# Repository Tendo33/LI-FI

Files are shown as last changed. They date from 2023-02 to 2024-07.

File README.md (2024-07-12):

# Li-Fi (Light Fidelity): Visible Light Communication Based on STM32

Innovative advancements in wireless communication have led to the development of Li-Fi, a technology that harnesses the power of visible light for data transmission. Li-Fi, or Light Fidelity, is a form of visible light communication (VLC) that uses light-emitting diodes (LEDs) as a medium for high-speed, bidirectional data transfer. This technology leverages the rapid switching capabilities of LEDs to transmit binary information, offering a new dimension to the realm of wireless networking.

At the heart of this cutting-edge system lies the STM32 microcontroller, a powerful and versatile device developed by STMicroelectronics. The STM32 family offers a wide range of performance, power consumption, and integration options, making it suitable for various applications, including complex high-end products and low-power devices. In the context of Li-Fi, the STM32 serves as the brain that controls the modulation and demodulation of light signals, enabling efficient and reliable data communication.

The STM32 microcontroller, with its robust processing capabilities, is capable of managing the intricate details of Li-Fi communication protocols. It can handle the modulation techniques required to encode digital data onto the light waves and decode them at the receiver end. Moreover, the STM32 can support additional functionalities such as error correction, signal processing, and security features, which are crucial for maintaining high data integrity and confidentiality in Li-Fi networks.

One of the significant advantages of using Li-Fi technology over traditional Wi-Fi is the potential for higher bandwidth and data rates. Since the visible light spectrum has a much wider bandwidth than radio frequencies, Li-Fi can theoretically achieve gigabit speeds. Additionally, Li-Fi can coexist harmoniously with existing wireless technologies without causing interference, making it a promising solution for densely populated areas or environments where radio frequency emissions are restricted, such as hospitals and aircraft cabins.

The integration of Li-Fi with the STM32 microcontroller opens up exciting possibilities for various industries. From enhancing the Internet of Things (IoT) ecosystem to improving connectivity in smart homes and offices, Li-Fi powered by STM32 can revolutionize the way we interact with our environment. With its ability to provide secure, high-speed connectivity using everyday lighting fixtures, Li-Fi stands as a beacon of innovation in the field of wireless communication.

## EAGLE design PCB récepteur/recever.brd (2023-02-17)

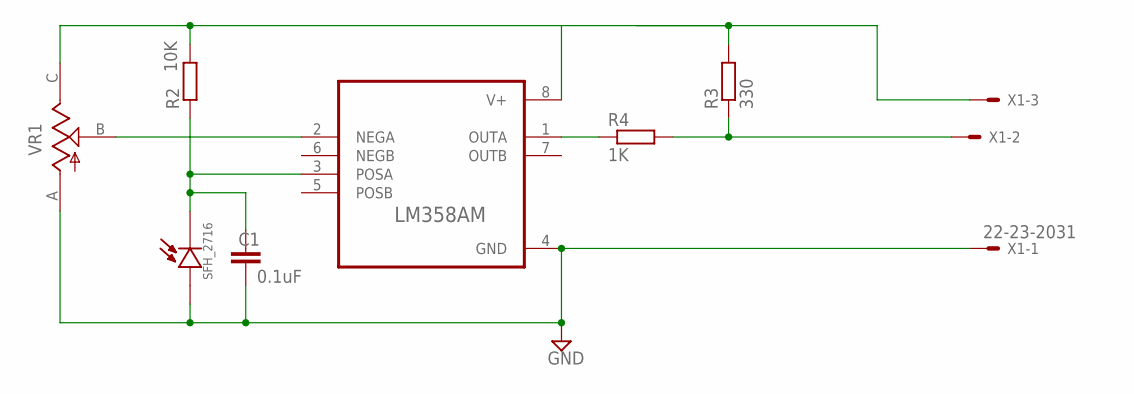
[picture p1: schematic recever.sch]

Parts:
C1: 0.1uF; C1206
D1: SFH_2716; LEDC2012X100N
R2: 10K; R1206
R3: 330; R1206
R4: 1K; R1206
U1: LM358AM; SOIC127P599X175-8N
VR1: 10K; TRIM_TS53YJ103MR10
X1: 22-23-2031

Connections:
GND: C1.2, D1.A, U1.4 (GND), VR1.A, X1.1
unnamed: R2.2, R3.2, U1.8 (V+), VR1.C, X1.3
unnamed: R3.1, R4.2, X1.2
unnamed: U1.2 (NEGA), VR1.B
unnamed: C1.1, D1.C, R2.1, U1.3 (POSA)
unnamed: R4.1, U1.1 (OUTA)

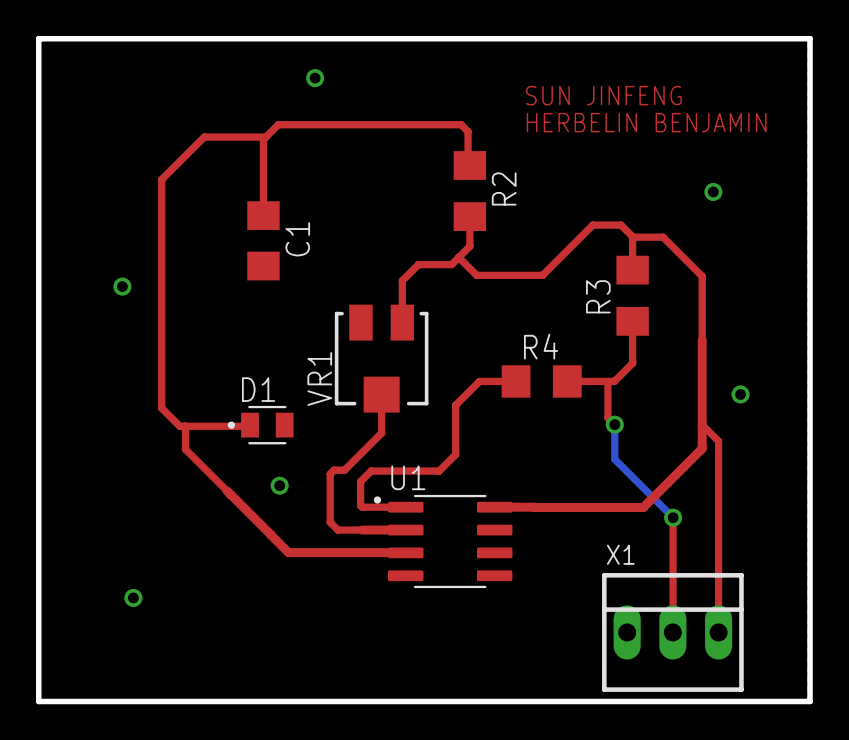
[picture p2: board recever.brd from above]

Board: 2 copper layers, 42.9 x 36.8 mm, 8 parts (0 on the bottom side), 6 nets.

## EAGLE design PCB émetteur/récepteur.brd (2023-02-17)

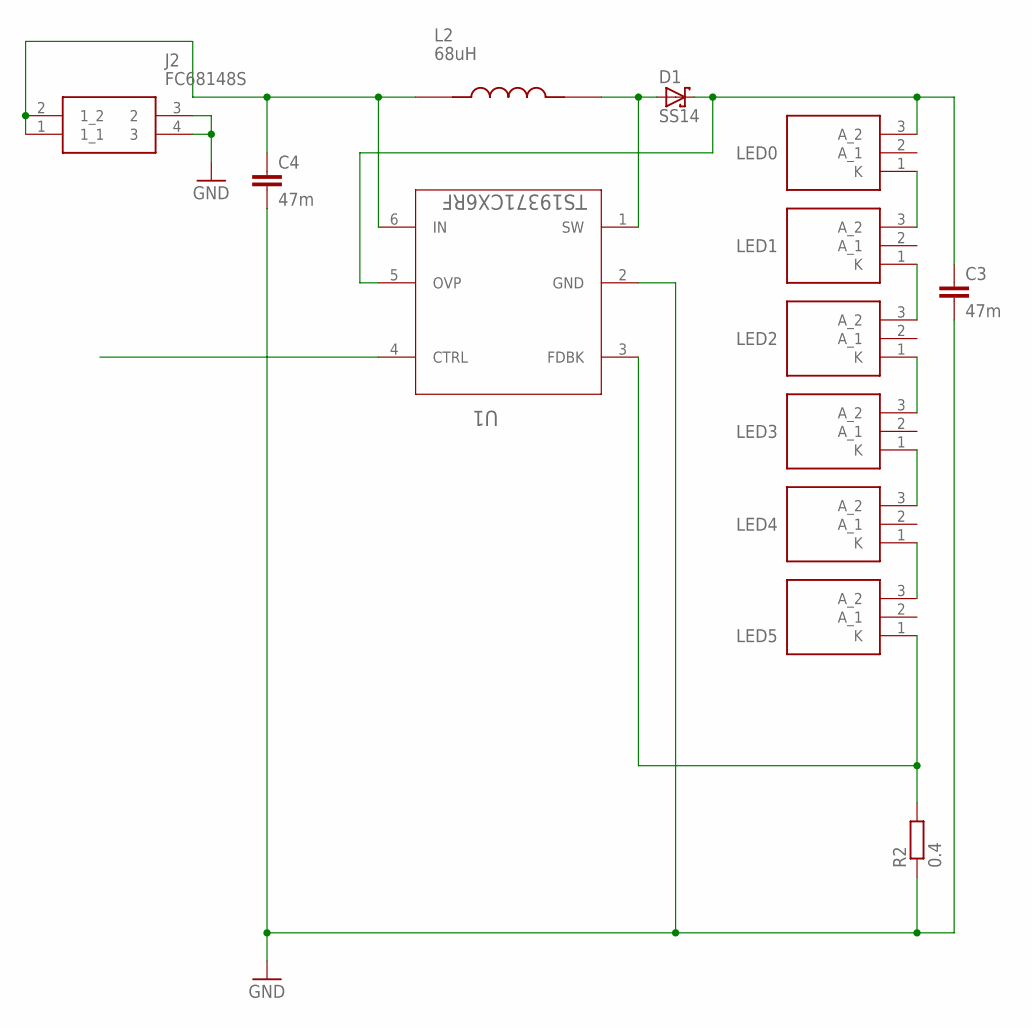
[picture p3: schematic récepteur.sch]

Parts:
C3, C4: 47m; C1206K
D1: SS14; DO-214AC
J2: FC68148S; FC68148S_2
L2: 68uH; IND_1255AY-680M=P3
LED0, LED1, LED2, LED3, LED4, LED5: LED-CREE-JK3030; JK3030AWT000000000A0HK230E
R2: 0.4; R1206
U1: TS19371CX6RF; SOT95P280X125-6N

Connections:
GND: C3.2, C4.2, J2.3 (2), J2.4 (3), R2.1, U1.2 (GND)
unnamed: LED0.1 (K), LED1.3 (A_2)
unnamed: LED1.1 (K), LED2.3 (A_2)
unnamed: LED2.1 (K), LED3.3 (A_2)
unnamed: LED3.1 (K), LED4.3 (A_2)
unnamed: LED4.1 (K), LED5.3 (A_2)
unnamed: LED5.1 (K), R2.2, U1.3 (FDBK)
unnamed: C4.1, J2.1 (1_1), J2.2 (1_2), L2.1, U1.6 (IN)
unnamed: D1.A, L2.2, U1.1 (SW)
unnamed: C3.1, D1.K, LED0.3 (A_2), U1.5 (OVP)

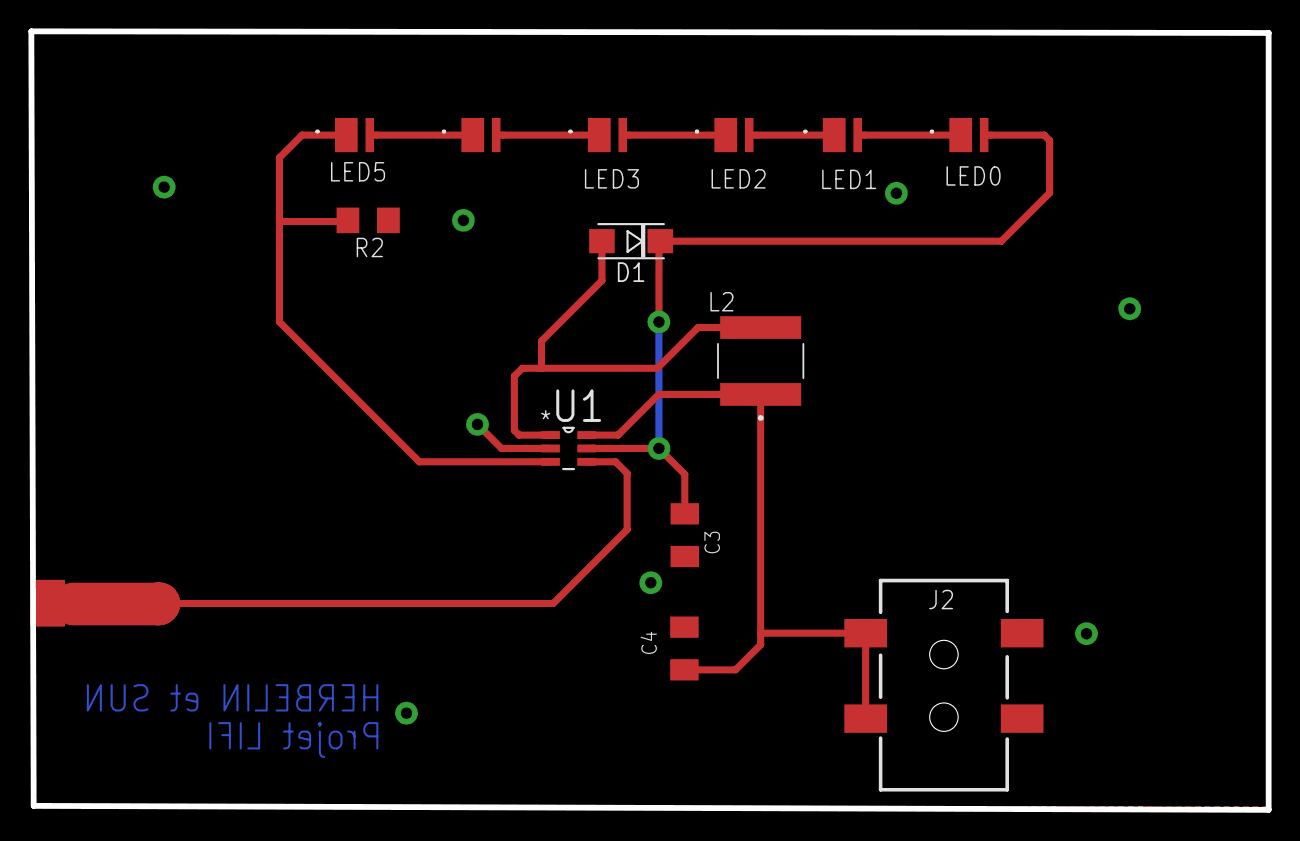
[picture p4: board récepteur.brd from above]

Board: 2 copper layers, 87.0 x 54.7 mm, 13 parts (0 on the bottom side), 10 nets.

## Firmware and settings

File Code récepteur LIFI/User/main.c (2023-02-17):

#include "MyIncludes.h"
#define  dataLen 12000

uint16_t dataCurrentPos=0;
uint16_t dataBuf[dataLen];
int main(void)
{	
	uint16_t recvWorkCounts=0;
	uint8_t j=0,startRecvFlag=0;
	uint16_t i=0,recvData,dataInfo[3]; //dataInfo_Utilis¨¦ pour v¨¦rifier les donn¨¦es de d¨¦but et de fin d'une r¨¦ception de donn¨¦es.
	uint16_t errorCounts=0; //Utilis¨¦ pour enregistrer le nombre de donn¨¦es recues en erreur.
	uint32_t recvTime_us;  //Permet d'enregistrer le temps pass¨¦ ¨¤ la r¨¦ception
	

	TIM3_CountTime_Init(); //Utilis¨¦ pour chronom¨¦trer la r¨¦ception des donn¨¦es
	  
	LdrConfigInit();//Initialisation des broches et de la fonction de capture d'entr¨¦e du capteur photosensible

	

	while(1)
	{
		recvData = receiveData();  //En attente de r¨¦ception d'une donn¨¦e
		
		if((!startRecvFlag) && recvData)  //Recevez d'abord les donn¨¦es de d¨¦but et de fin, puis la longueur totale.
		{
			dataInfo[j] = recvData;
			j++;
			if(j==3)
			{
				j = 0; //Si end + 1 - start = length, pr¨ºt ¨¤ Recevoir des donn¨¦es.
				if((dataInfo[1]+1-dataInfo[0]) == dataInfo[2]) startRecvFlag = 1; 
				else printf("Cette r¨¦ception a ¨¦chou¨¦ ! Veuillez renvoyer les donn¨¦es !\r\n");
			}
		}
		
		if(startRecvFlag) //Commencer ¨¤ recevoir des donn¨¦es
		{
			printf("receiving...\r\n");
			startRecvFlag = 0;
			startCountRunningTime(); //D¨¦marrer l'horloge
			for(i=dataInfo[0];i<(dataInfo[1]+1);i++) //R¨¦ception cyclique des donn¨¦es
			{
				recvData = receiveData();  
				if(recvData==i) dataBuf[dataCurrentPos++] = recvData;
				else 
				{
					if(recvData!=0) 
					{
						dataCurrentPos = recvData-i;
						dataBuf[dataCurrentPos++] = recvData;
						i = recvData;
					}
				}					
			}
			recvTime_us = getRunningTime(); //Terminez la r¨¦ception, puis chronom¨¦trez-la et obtenez l'heure.

			
			printf("R¨¦ception termin¨¦e ! Donn¨¦es en cours de v¨¦rification¡­¡­\r\n");  //Donn¨¦es d'inspection
			dataCurrentPos=0;
			for(i=dataInfo[0];i<(dataInfo[1]+1);i++)
			{
				if(dataBuf[dataCurrentPos]!=i) 
				{
					errorCounts++;
					printf("¡¾err¡¿ ");
				}
				else printf("%d ",dataBuf[dataCurrentPos]);
				dataCurrentPos++;
			}
			recvWorkCounts++;
			
			errorCounts = 0;
			recvData = 0;
			dataCurrentPos=0;
			memset(dataBuf,0,sizeof(dataBuf));
			printf("En attente de r¨¦ception de donn¨¦es¡­¡­\r\n");
		}
	}
}

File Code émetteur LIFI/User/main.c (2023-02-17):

#include "Myincludes.h"
#include "delay.h"
#include "sensor.h"


#define RECV_LENGTH	100		//Longueur du tampon de r¨¦ception
#define SEND_LENGTH	100	  	//Longueur du tampon d'envoi

u8 test_txbuf[100];
u8 test_rxbuf[100];
u8 tx_index = 0;
u8 send_len;                  //Longueur d'envoi
u8 recv_len;                  //Longueur de r¨¦ception
u8 recv_timeout = 0;              //timeout
u8 recv_complete = 0;             //R¨¦ception termin¨¦e

//Transmission de donn¨¦es en continu
void emitSeriesData(uint16_t start,uint16_t end)
{
	uint16_t i;
	uint16_t len=end+1;
	
	if((start>0) && (end>start))
	{
		
		emitData(start); 
		emitData(end); 
		emitData((end+1-start)); //Envoyez d'abord l'information de ce bloc de donn¨¦es
		delay_ms(10);
		
		for(i=start;i<len;i++) 
		{
			emitData(i); //D¨¦but de l'envoi cyclique, en commen?ant par le bit de donn¨¦es de d¨¦part.
			
		}
		LED1;//Fin de l'envoi par d¨¦faut LED est lumineux
		
	}
}


int main(void)
{	
	System_Init();
	  
	LED_Init();//Initialisation des broches de la source lumineuse
	
	LED1;  //Source lumineuse par d¨¦faut allum¨¦e avant le lancement
	
	
	while(1)
	{
		
		emitSeriesData(1,100);//Signaux transmis
		
	}
}

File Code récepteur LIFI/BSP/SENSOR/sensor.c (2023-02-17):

#include "sensor.h"

#include "Timerx.h"

#define DATABIT 14

extern u8  TIM5CH1_CAPTURE_STA;

uint32_t startSignal_time;
uint32_t data_0_time;
uint32_t data_1_time;
uint32_t upperAddValue;
uint32_t lowerDecValue;

uint32_t start_upperBound,start_lowerBound;
uint32_t data_0_upperBound,data_1_upperBound,data_0_lowerBound,data_1_lowerBound;  

void LdrConfigInit()
{
	TIM5_Cap_Init(); 
	startSignal_time = 600; 
	data_0_time = 800; 
	data_1_time = 1000; 
	upperAddValue = 100; 
	lowerDecValue = 100;
	
	start_upperBound  = startSignal_time+upperAddValue;
	start_lowerBound  = startSignal_time-lowerDecValue;
	data_0_upperBound = data_0_time+upperAddValue;
	data_0_lowerBound = data_0_time-lowerDecValue;
	data_1_upperBound = data_1_time+upperAddValue;
	data_1_lowerBound = data_1_time-lowerDecValue;
}

uint16_t receiveData()
{
	uint32_t highVolTime = 0;
	short int dataBit = DATABIT;
	uint8_t dataFlag = 0;
	uint16_t data = 0;
	while(1)
	{
		if(TIM5CH1_CAPTURE_STA&0X80) //Capture r¨¦ussie du signal de d¨¦part
		{
			highVolTime = getHighVolTime();
			if((highVolTime<=start_upperBound) && (highVolTime>=start_lowerBound)) //Signal de premier d¨¦marrage correct
			{
				while(1)
				{
					if(TIM5CH1_CAPTURE_STA&0X80) 
					{
						highVolTime = getHighVolTime();
						if((highVolTime>=data_0_lowerBound) && (highVolTime<=data_0_upperBound))
						{
							data &= ~(1<<(dataBit-1));
							dataBit--;
							if(dataBit==0)
							{
								dataFlag = 1;break;
							}
						}
						else if((highVolTime>=data_1_lowerBound) && (highVolTime<=data_1_upperBound))
						{
							data |= (1<<(dataBit-1));
							dataBit--;
							if(dataBit==0)
							{
								dataFlag = 1;break;
							}
						}
						else {printf("dataError:highVolTime:%d\r\n",highVolTime);break;}
					}
				}
				break;
			}
			else printf("startError:highVolTime:%d\r\n",highVolTime);
		}
	}
	if(dataFlag) return data;
	else return 0;
}

//pour configurer les param¨¨tres li¨¦s ¨¤ la r¨¦ception.
void configRecvParameter(uint32_t p1,uint32_t p2,uint32_t p3,uint32_t p4,uint32_t p5)
{
		startSignal_time = p1; 
		data_0_time = p2;  
	  data_1_time = p3;  
		upperAddValue = p4;  
		lowerDecValue = p5; 
	
		start_upperBound  = startSignal_time+upperAddValue;
		start_lowerBound  = startSignal_time-lowerDecValue;
		data_0_upperBound = data_0_time+upperAddValue;
		data_0_lowerBound = data_0_time-lowerDecValue;
		data_1_upperBound = data_1_time+upperAddValue;
		data_1_lowerBound = data_1_time-lowerDecValue;
}

void lookUpCurrentParameter() //Visualiser les param¨¨tres de lancement actuels
{
	printf("HoldTime:     start: %d  0 signal: %d  1 signal: %d\r\nWaitTime:    upper: %d  lower: %d\r\n", \
				startSignal_time,data_0_time,data_1_time, \
				upperAddValue,lowerDecValue);
}
